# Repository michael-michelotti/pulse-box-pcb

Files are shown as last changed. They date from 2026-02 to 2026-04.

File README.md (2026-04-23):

# Pulse Box PCB

KiCad 9.0 hardware designs for the [PulseBox](https://github.com/michael-michelotti/pulse-box-esp) project — a modular LED grid system with a central controller driving a dynamically reconfigurable array of 8x8 LED panels. This repo holds the schematics, board layouts, and JLCPCB manufacturing outputs for all board revisions.

This is meant as a companion to the [main PulseBox repo](https://github.com/michael-michelotti/pulse-box-esp) — see that repo for the full system overview.

---

## Controller v1 (`Pulse_Box_PCB_v1/`)

<!-- TODO: Replace with labeled photo of v1 controller board -->

Controller v1

Original controller, fabricated and assembled by JLCPCB. 2-layer board built around an **STM32F407VGT6** (ARM Cortex-M4, LQFP-100). Power comes in through a 5.5mm barrel jack and is regulated by a **TPSM53604RDA** 4A buck module (down to 5V), followed by an **AP2112K-3.3** LDO for the 3.3V MCU rail. LED data is level-shifted from 3.3V to 5V through a **SN74LV1T34** before driving the WS2812B chain. USB Micro-B for serial/flashing.

---

## Controller v2 (`Pulse_Box_PCB_v2/`)

<!-- TODO: Replace with labeled photo of v2 controller board -->

Controller v2

Redesigned controller centered on the **ESP32-S3-WROOM-1** module (WiFi, BLE, dual-core). 2-layer, 80mm x 80mm. The barrel jack is replaced with a 24V input to match the rest of the panel bus, and the buck module is swapped for a **discrete TPS54560B** design (24V→5V, 5A) with an **AP2112K-3.3** LDO for the 3.3V rail. USB-C exposes the ESP32-S3's native USB-JTAG for debug. Dual **SN74LV1T34** level shifters drive LED data north and west, and panel interconnect is 8-pin (24V, GND, RS-485 A/B, sense, LED data).

---

## Panel v1 (`Pulse_Box_Panel_v1/`)

<!-- TODO: Replace with labeled photo of panel board -->

Panel v1

LED panel board, 2-layer, 80mm x 80mm. Runs an **STM32G071C8** (Cortex-M0+, LQFP-48) with four USARTs — one per edge — so adjacent panels mate face-to-face with no crossover. Power mirrors the v2 controller: 24V bus in, discrete buck to 5V for the LEDs, **AP2112K-3.3** LDO for the 3.3V MCU rail. LED data routing uses two **74HC4051** 8-channel analog muxes (one for input, one for output) so any edge can be selected as the data in/out for the panel's 8x8 grid. Four JST XH 11-position edge connectors carry 24V, GND, UART TX/RX, sense, and LED data. SWD header for debug; UART bootloader available on PA2/PA3 as a recovery path.

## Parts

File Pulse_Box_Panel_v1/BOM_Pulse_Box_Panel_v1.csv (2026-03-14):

Comment | Designator | Footprint | JLCPCB Part #
10uF | C1,C2,C3,C9,C11 | Capacitor_SMD:C_0805_2012Metric | C440198
11nF | C4 | Capacitor_SMD:C_0805_2012Metric | C710944
8.2pF | C5 | Capacitor_SMD:C_0402_1005Metric | C1579
100nF | C6,C10,C12,C13,C16 | Capacitor_SMD:C_0402_1005Metric | C1525
47uF | C7,C8 | Capacitor_SMD:C_0805_2012Metric | C76636
20pF | C14,C15 | Capacitor_SMD:C_0402_1005Metric | C1554
100uF | C17,C18,C19 | Capacitor_SMD:C_Elec_8x10.2 | C3352
SS310 | D1 | Diode_SMD:D_SMB | C14651
LED | D3,D4 | LED_SMD:LED_0402_1005Metric | C71911
Conn_01x11 | J1,J2,J3,J4 | Connector_JST:JST_XH_B11B-XH-A_1x11_P2.50mm_Vertical | C158031
Conn_01x03 | J5,J6 | Connector_JST:JST_PH_B3B-PH-K_1x03_P2.00mm_Vertical | C131339
Conn_01x04_Pin | J7 | Connector_PinHeader_2.54mm:PinHeader_1x04_P2.54mm_Vertical | C124378
Conn_01x03 | J8 | Connector_PinHeader_2.54mm:PinHeader_1x03_P2.54mm_Vertical | C49257
Conn_02x05_Odd_Even | J9 | Connector_PinHeader_1.27mm:PinHeader_2x05_P1.27mm_Vertical | C239059
10uH | L1 | Inductor_SMD:L_TechFuse_SL1040 | C22463839
274k | R1 | Resistor_SMD:R_0402_1005Metric | C27004
15.8k | R2 | Resistor_SMD:R_0402_1005Metric | C26956
60k | R3 | Resistor_SMD:R_0402_1005Metric | C25911
11.5k | R4 | Resistor_SMD:R_0402_1005Metric | C159139
470 | R11,R12 | Resistor_SMD:R_0402_1005Metric | C25117
STM32G0B1CBTx | U1 | Package_QFP:LQFP-48_7x7mm_P0.5mm | C529341
TPS54560BDDA | U2 | Package_SO:Texas_R-PDSO-G8_EP2.95x4.9mm_Mask2.4x3.1mm_ThermalVias | C1850354
AP2112K-3.3 | U3 | Package_TO_SOT_SMD:SOT-23-5 | C3021085
74HCT4051 | U4,U5 | Package_SO:TSSOP-16_4.4x5mm_P0.65mm | C192055
8MHz Crystal | Y1 | Crystal:Crystal_SMD_3225-4Pin_3.2x2.5mm | C57131

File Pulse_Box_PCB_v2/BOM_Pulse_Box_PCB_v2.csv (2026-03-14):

Comment | Designator | Footprint | JLCPCB Part #
470uF | C1 | Capacitor_SMD:CP_Elec_10x12.6 | C90272
10uF | C2,C3,C4 | Capacitor_SMD:C_0805_2012Metric | C440198
11nF | C5 | Capacitor_SMD:C_0805_2012Metric | C710944
8.2pF | C6 | Capacitor_SMD:C_0402_1005Metric | C1579
100nF | C7,C12,C13,C14,C15,C16 | Capacitor_SMD:C_0402_1005Metric | C1525
47uF | C8,C9 | Capacitor_SMD:C_0805_2012Metric | C76636
4.7uF | C10,C11 | Capacitor_SMD:C_0805_2012Metric | C1779
22uF | C17 | Capacitor_SMD:C_1206_3216Metric_Pad1.33x1.80mm_HandSolder | C12891
1uF | C18 | Capacitor_SMD:C_0402_1005Metric | C52923
SS310 | D1 | Diode_SMD:D_SMB | C14651
LED | D3,D4 | LED_SMD:LED_0402_1005Metric | C71911
Screw_Terminal_01x02 | J1 | TerminalBlock_Phoenix:TerminalBlock_Phoenix_MKDS-1,5-2-5.08_1x02_P5.08mm_Horizontal | C8465
Conn_01x11 | J2,J3 | Connector_JST:JST_XH_B11B-XH-A_1x11_P2.50mm_Vertical | C158031
Conn_01x03 | J4,J5 | Connector_JST:JST_PH_B3B-PH-K_1x03_P2.00mm_Vertical | C131339
Conn_01x03_Pin | J6 | Connector_PinHeader_2.54mm:PinHeader_1x03_P2.54mm_Vertical | C49257
Conn_01x04 | J7 | Connector_PinHeader_2.54mm:PinHeader_1x04_P2.54mm_Vertical | C124378
10uH | L1 | Inductor_SMD:L_TechFuse_SL1040 | C22463839
USB_C_Plug_USB2.0 | P1 | Connector_USB:USB_C_Receptacle_HRO_TYPE-C-31-M-12 | C165948
274k | R1 | Resistor_SMD:R_0402_1005Metric | C27004
15.8k | R2 | Resistor_SMD:R_0402_1005Metric | C26956
60k | R3 | Resistor_SMD:R_0402_1005Metric | C25911
11.5k | R4 | Resistor_SMD:R_0402_1005Metric | C159139
22 | R5,R6 | Resistor_SMD:R_0402_1005Metric | C25092
10k | R7,R8,R11,R12 | Resistor_SMD:R_0402_1005Metric | C25744
470 | R9,R10 | Resistor_SMD:R_0402_1005Metric | C25117
5.1k | R13 | Resistor_SMD:R_0402_1005Metric | C25905
SW_Push | SW1,SW2 | Button_Switch_SMD:SW_Push_SPST_NO_Alps_SKRK | C398055
ESP32-S3-WROOM-1 | U1 | RF_Module:ESP32-S3-WROOM-1 | C2913197
USBLC6-2SC6 | U2 | Package_TO_SOT_SMD:SOT-23-6 | C558442
TPS54560BDDA | U3 | Package_SO:Texas_R-PDSO-G8_EP2.95x4.9mm_Mask2.4x3.1mm_ThermalVias | C1850354
SN74LV1T34DBV | U4,U6 | Package_TO_SOT_SMD:SOT-23-5 | C100024
74LVC1G3157 | U5 | Package_TO_SOT_SMD:SOT-23-6 | C10426
AP2114-3.3TRG1 | U7 | Package_TO_SOT_SMD:SOT-223-3_TabPin2 | C460314

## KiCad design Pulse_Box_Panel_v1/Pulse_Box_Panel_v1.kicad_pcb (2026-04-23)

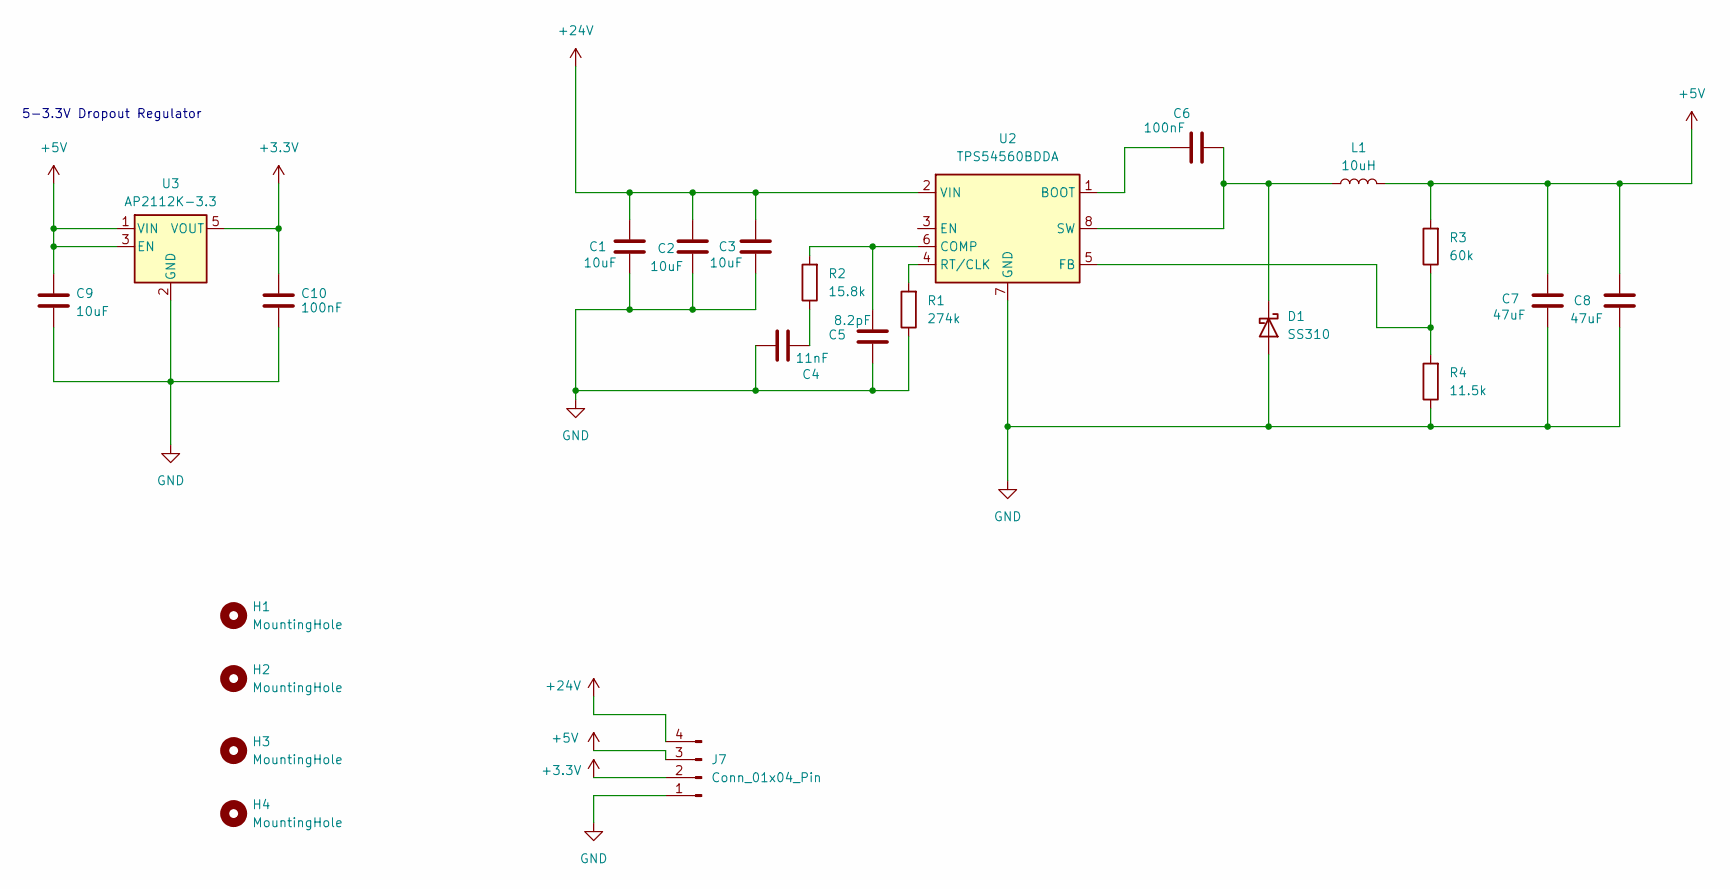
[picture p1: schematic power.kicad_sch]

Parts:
C1, C2, C3: 10uF; C_0805_2012Metric; JLCPCB Part # C440198
C4: 11nF; C_0805_2012Metric; JLCPCB Part # C710944
C5: 8.2pF; C_0402_1005Metric; JLCPCB Part # C1579
C6: 100nF; C_0402_1005Metric; JLCPCB Part # C1525
C7, C8: 47uF; C_0805_2012Metric; JLCPCB Part # C76636
C9: 10uF; C_0805_2012Metric; MFR PN CL21A106KAYNNNE; JLCPCB PN C15850
C10: 100nF; C_0402_1005Metric; MFR PN CL21A475KAQNNNE; JLCPCB PN C1779
D1: SS310; D_SMB; JLCPCB Part # C14651
H1, H2, H3, H4: MountingHole; MountingHole_3.2mm_M3
J7: Conn_01x04_Pin; PinHeader_1x04_P2.54mm_Vertical; JLCPCB Part # C124378
L1: 10uH; L_TechFuse_SL1040; JLCPCB Part # C22463839
R1: 274k; R_0402_1005Metric; JLCPCB Part # C27004
R2: 15.8k; R_0402_1005Metric; JLCPCB Part # C26956
R3: 60k; R_0402_1005Metric; JLCPCB Part # C25911
R4: 11.5k; R_0402_1005Metric; JLCPCB Part # C159139
U2: TPS54560BDDA; Texas_R-PDSO-G8_EP2.95x4.9mm_Mask2.4x3.1mm_ThermalVias; JLCPCB Part # C1850354
U3: AP2112K-3.3; SOT-23-5; MFR PN AP2112K-3.3; JLCPCB PN C23380830

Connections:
+3.3V: C10.1, J7.2, U3.5 (VOUT); also elsewhere on the board
+5V: C7.1, C8.1, C9.1, J7.3, L1.2, R3.2, U3.1 (VIN), U3.3 (EN); also elsewhere on the board
+24V: C1.1, C2.1, C3.1, J7.4, U2.2 (VIN); also elsewhere on the board
GND: C1.2, C2.2, C3.2, C4.1, C5.2, C7.2, C8.2, C9.2, C10.2, D1.2 (A), J7.1, R1.1, R4.1, U2.7 (GND), U2.9 (GND), U3.2 (GND); also elsewhere on the board
unnamed: C4.2, R2.1
unnamed: C6.2, D1.1 (K), L1.1, U2.8 (SW)
unnamed: C6.1, U2.1 (BOOT)
unnamed: C5.1, R2.2, U2.6 (COMP)
unnamed: R3.1, R4.2, U2.5 (FB)
unnamed: R1.2, U2.4 (RT/CLK)

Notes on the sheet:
5-3.3V Dropout Regulator

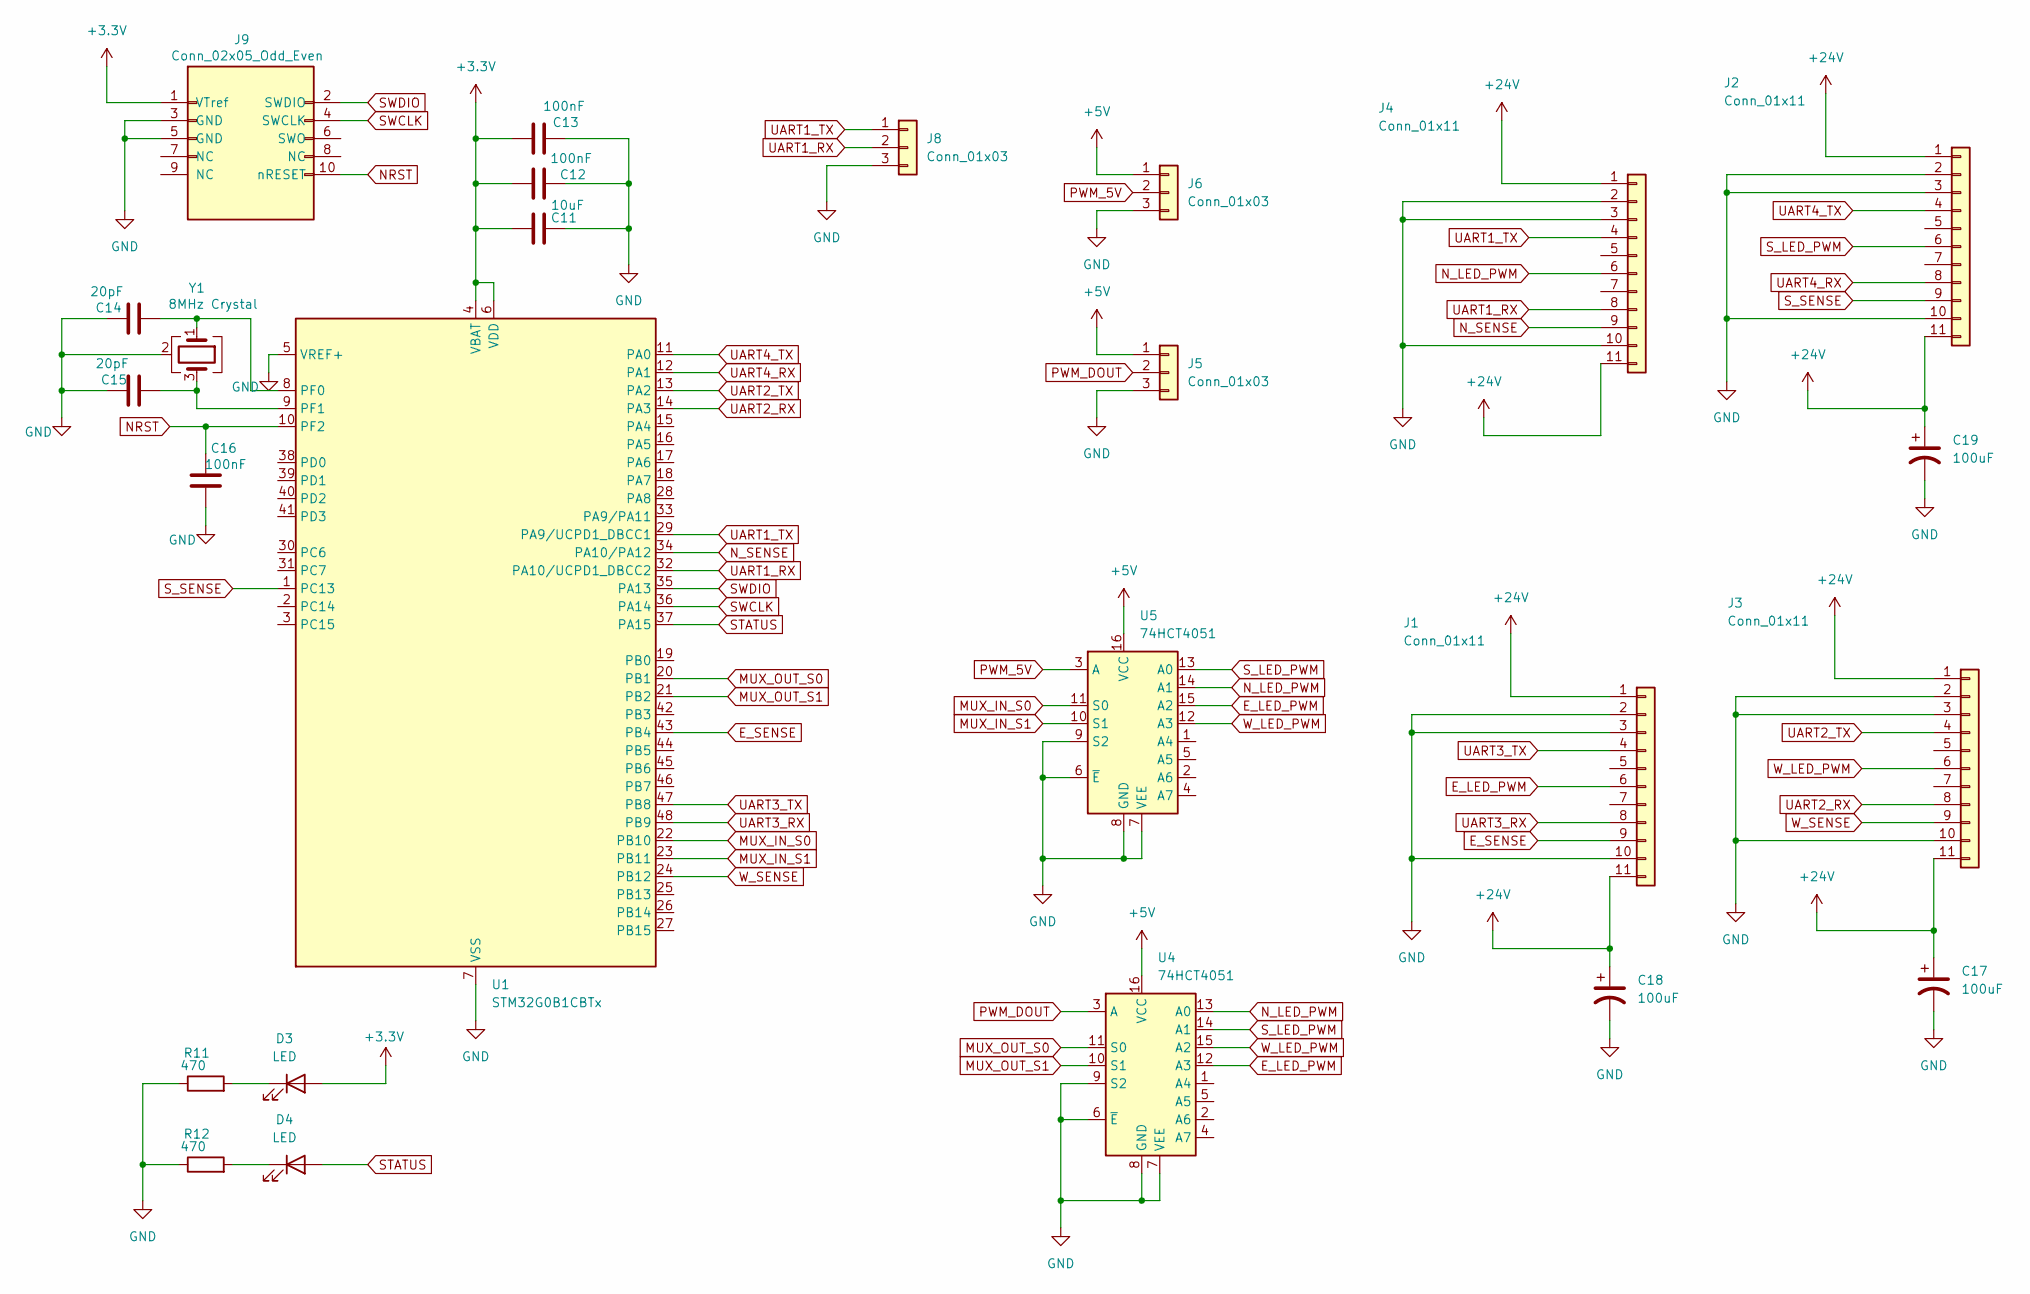
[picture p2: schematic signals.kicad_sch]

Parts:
C11: 10uF; C_0805_2012Metric; JLCPCB Part # C440198
C12, C13, C16: 100nF; C_0402_1005Metric; JLCPCB Part # C1525
C14, C15: 20pF; C_0402_1005Metric; JLCPCB Part # C1554
C17, C18, C19: 100uF; C_Elec_8x10.2; JLCPCB Part # C3352
D3, D4: LED; LED_0402_1005Metric; JLCPCB Part # C71911
J1, J2, J3, J4: Conn_01x11; JST_XH_B11B-XH-A_1x11_P2.50mm_Vertical; JLCPCB Part # C158031
J5, J6: Conn_01x03; JST_PH_B3B-PH-K_1x03_P2.00mm_Vertical; JLCPCB Part # C131339
J8: Conn_01x03; PinHeader_1x03_P2.54mm_Vertical; JLCPCB Part # C49257
J9: Conn_02x05_Odd_Even; PinHeader_2x05_P1.27mm_Vertical; MFR PN 20021111-00010T4LF; JLCPCB PN C239059
R11, R12: 470; R_0402_1005Metric; JLCPCB Part # C25117
U1: STM32G0B1CBTx; LQFP-48_7x7mm_P0.5mm; JLCPCB Part # C529341
U4, U5: 74HCT4051; TSSOP-16_4.4x5mm_P0.65mm; JLCPCB Part # C192055
Y1: 8MHz Crystal; Crystal_SMD_3225-4Pin_3.2x2.5mm; MFR PN 1C208000BC0R; JLCPCB PN C57131

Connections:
+3.3V: C11.1, C12.1, C13.1, D3.2 (A), J9.1 (VTref), U1.4 (VBAT), U1.6 (VDD); also elsewhere on the board
+5V: J5.1, J6.1, U4.16 (VCC), U5.16 (VCC); also elsewhere on the board
+24V: C17.1, C18.1, C19.1, J1.1, J1.11, J2.1, J2.11, J3.1, J3.11, J4.1, J4.11; also elsewhere on the board
E_LED_PWM: J1.6, U4.12 (A3), U5.15 (A2)
E_SENSE: J1.9, U1.43 (PB4)
GND: C11.2, C12.2, C13.2, C14.1, C15.1, C16.1, C17.2, C18.2, C19.2, J1.2, J1.3, J1.10, J2.2, J2.3, J2.10, J3.2, J3.3, J3.10, J4.2, J4.3, J4.10, J5.3, J6.3, J8.3, J9.3 (GND), J9.5 (GND), R11.1, R12.1, U1.5 (VREF+), U1.7 (VSS), U4.6 (~E), U4.7 (VEE), U4.8 (GND), U4.9 (S2), U5.6 (~E), U5.7 (VEE), U5.8 (GND), U5.9 (S2), Y1.2 (G), Y1.4 (G); also elsewhere on the board
MUX_IN_S0: U1.22 (PB10), U5.11 (S0)
MUX_IN_S1: U1.23 (PB11), U5.10 (S1)
MUX_OUT_S0: U1.20 (PB1), U4.11 (S0)
MUX_OUT_S1: U1.21 (PB2), U4.10 (S1)
NRST: C16.2, J9.10 (nRESET), U1.10 (PF2)
N_LED_PWM: J4.6, U4.13 (A0), U5.14 (A1)
N_SENSE: J4.9, U1.34 (PA10/PA12)
unnamed: D3.1 (K), R11.2
unnamed: D4.1 (K), R12.2
unnamed: C14.2, U1.8 (PF0), Y1.1
unnamed: C15.2, U1.9 (PF1), Y1.3
PWM_5V: J6.2, U5.3 (A)
PWM_DOUT: J5.2, U4.3 (A)
STATUS: D4.2 (A), U1.37 (PA15)
SWCLK: J9.4 (SWCLK), U1.36 (PA14)
SWDIO: J9.2 (SWDIO), U1.35 (PA13)
S_LED_PWM: J2.6, U4.14 (A1), U5.13 (A0)
S_SENSE: J2.9, U1.1 (PC13)
UART1_RX: J4.8, J8.2, U1.32 (PA10/UCPD1_DBCC2)
UART1_TX: J4.4, J8.1, U1.29 (PA9/UCPD1_DBCC1)
UART2_RX: J3.8, U1.14 (PA3)
UART2_TX: J3.4, U1.13 (PA2)
UART3_RX: J1.8, U1.48 (PB9)
UART3_TX: J1.4, U1.47 (PB8)
UART4_RX: J2.8, U1.12 (PA1)
UART4_TX: J2.4, U1.11 (PA0)
W_LED_PWM: J3.6, U4.15 (A2), U5.12 (A3)
W_SENSE: J3.9, U1.24 (PB12)

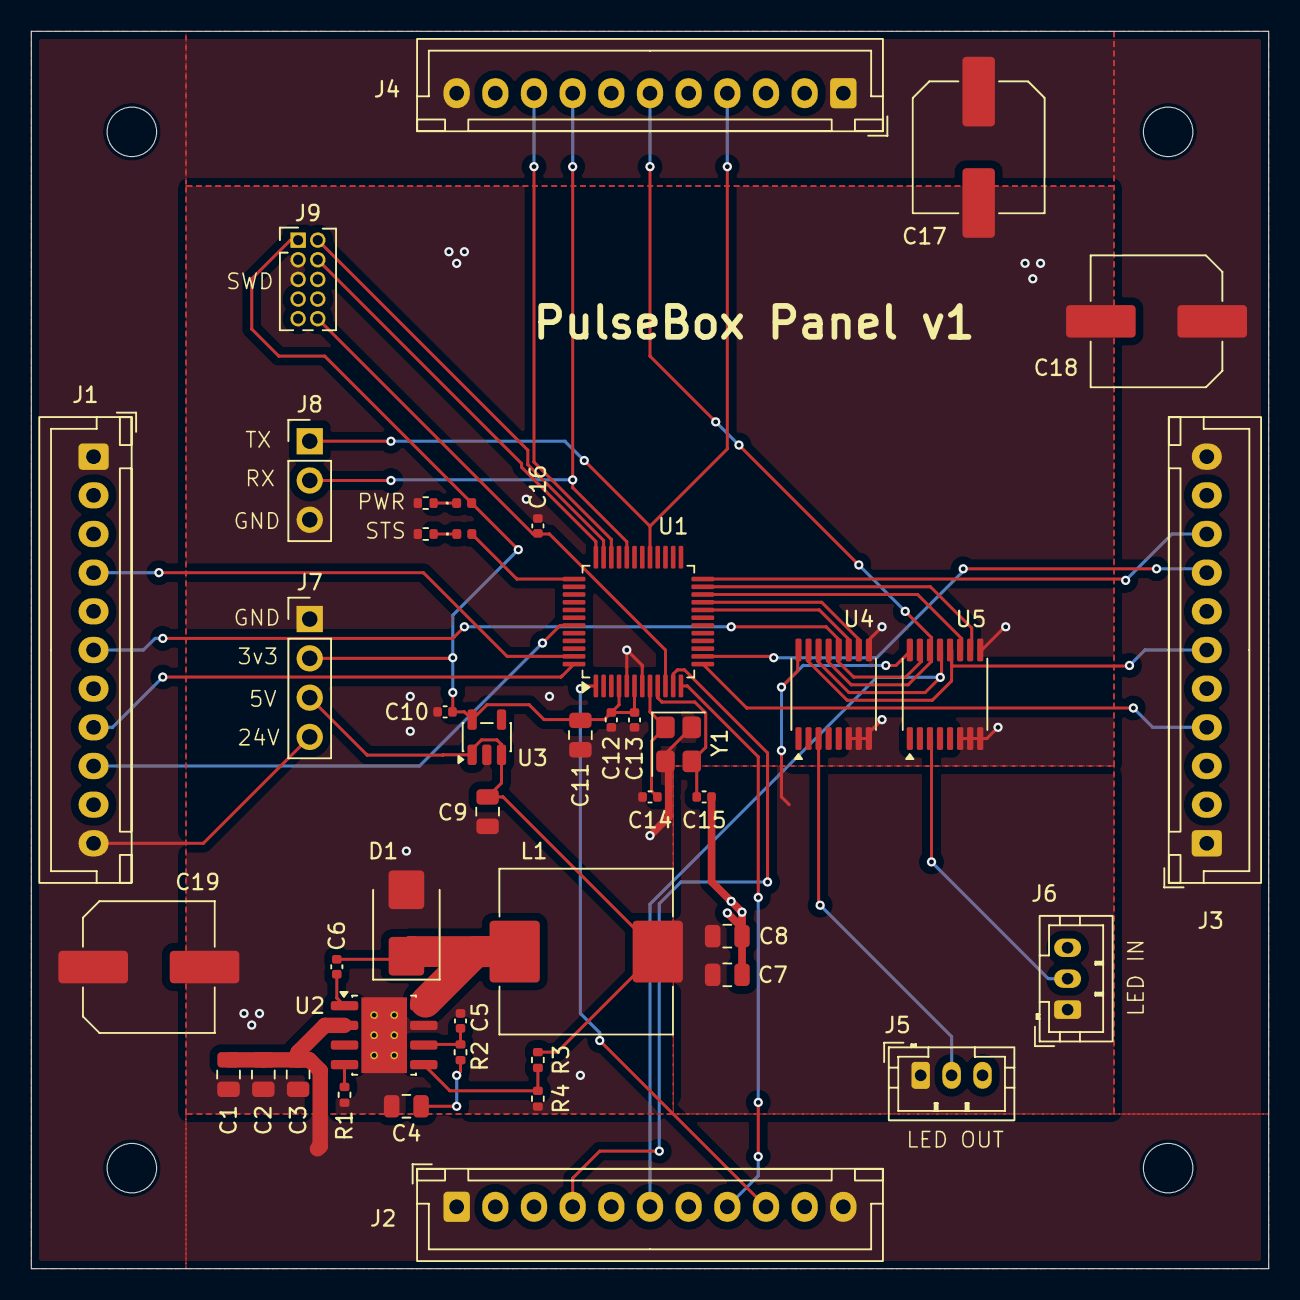
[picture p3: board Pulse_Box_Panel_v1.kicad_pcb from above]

Board: 2 copper layers, 80.0 x 80.0 mm, 48 parts (0 on the bottom side), 40 nets.

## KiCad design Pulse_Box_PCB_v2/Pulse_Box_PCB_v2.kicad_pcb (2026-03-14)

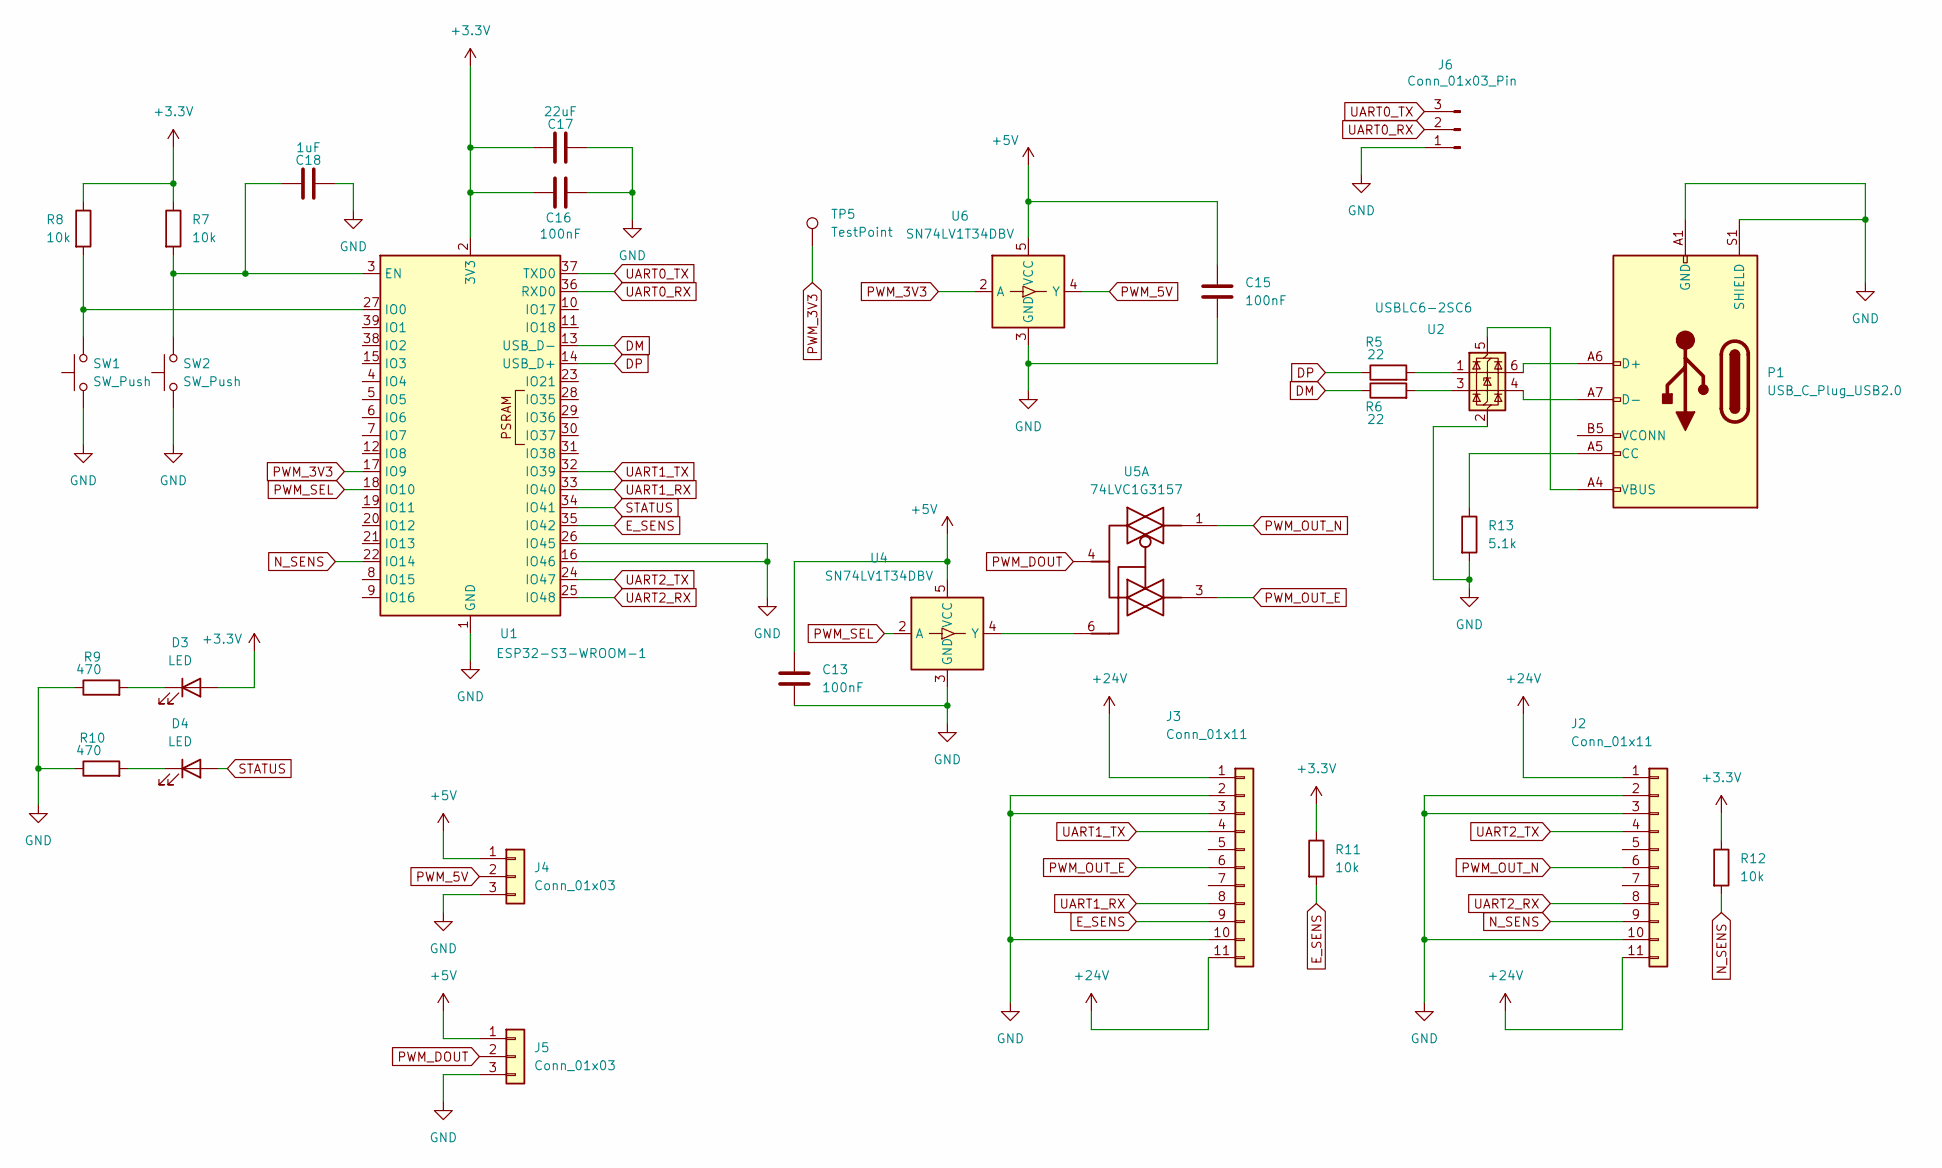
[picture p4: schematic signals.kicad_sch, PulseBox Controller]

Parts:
C13, C15, C16: 100nF; C_0402_1005Metric; JLCPCB Part # C1525
C17: 22uF; C_1206_3216Metric_Pad1.33x1.80mm_HandSolder; JLCPCB Part # C12891
C18: 1uF; C_0402_1005Metric; JLCPCB Part # C52923
D3, D4: LED; LED_0402_1005Metric; JLCPCB Part # C71911
J2, J3: Conn_01x11; JST_XH_B11B-XH-A_1x11_P2.50mm_Vertical; JLCPCB Part # C158031
J4, J5: Conn_01x03; JST_PH_B3B-PH-K_1x03_P2.00mm_Vertical; JLCPCB Part # C131339
J6: Conn_01x03_Pin; PinHeader_1x03_P2.54mm_Vertical; JLCPCB Part # C49257
P1: USB_C_Plug_USB2.0; USB_C_Receptacle_HRO_TYPE-C-31-M-12; JLCPCB Part # C165948
R5, R6: 22; R_0402_1005Metric; JLCPCB Part # C25092
R7, R8, R11, R12: 10k; R_0402_1005Metric; JLCPCB Part # C25744
R9, R10: 470; R_0402_1005Metric; JLCPCB Part # C25117
R13: 5.1k; R_0402_1005Metric; JLCPCB Part # C25905
SW1, SW2: SW_Push; SW_Push_SPST_NO_Alps_SKRK; JLCPCB Part # C398055
TP5: TestPoint; TestPoint_Pad_2.0x2.0mm
U1: ESP32-S3-WROOM-1; JLCPCB Part # C2913197
U2: USBLC6-2SC6; SOT-23-6; JLCPCB Part # C558442
U4, U6: SN74LV1T34DBV; SOT-23-5; JLCPCB Part # C100024
U5: 74LVC1G3157; SOT-23-6; JLCPCB Part # C10426

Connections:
+3.3V: C16.2, C17.2, D3.2 (A), R7.1, R8.1, R11.1, R12.1, U1.2 (3V3); also elsewhere on the board
+5V: C13.1, C15.1, J4.1, J5.1, U4.5 (VCC), U6.5 (VCC); also elsewhere on the board
+24V: J2.1, J2.11, J3.1, J3.11; also elsewhere on the board
DM: R6.1, U1.13 (USB_D-)
DP: R5.1, U1.14 (USB_D+)
E_SENS: J3.9, R11.2, U1.35 (IO42)
GND: C13.2, C15.2, C16.1, C17.1, C18.1, J2.2, J2.3, J2.10, J3.2, J3.3, J3.10, J4.3, J5.3, J6.1, P1.A1 (GND), P1.A12 (GND), P1.B1 (GND), P1.B12 (GND), P1.S1 (SHIELD), R9.1, R10.1, R13.2, SW1.1, SW2.1, U1.1 (GND), U1.16 (IO46), U1.26 (IO45), U1.40 (GND), U1.41 (GND), U2.2 (GND), U4.3 (GND), U6.3 (GND); also elsewhere on the board
N_SENS: J2.9, R12.2, U1.22 (IO14)
unnamed: D3.1 (K), R9.2
unnamed: D4.1 (K), R10.2
unnamed: P1.A5 (CC), R13.1
unnamed: P1.A6 (D+), U2.6 (I/O1)
unnamed: P1.A7 (D-), U2.4 (I/O2)
unnamed: R5.2, U2.1 (I/O1)
unnamed: R6.2, U2.3 (I/O2)
unnamed: C18.2, R7.2, SW2.2, U1.3 (EN)
unnamed: R8.2, SW1.2, U1.27 (IO0)
unnamed: P1.A4 (VBUS), P1.A9 (VBUS), P1.B4 (VBUS), P1.B9 (VBUS), U2.5 (VBUS)
unnamed: U4.4 (Y), U5.6
PWM_3V3: TP5.1, U1.17 (IO9), U6.2 (A)
PWM_5V: J4.2, U6.4 (Y)
PWM_DOUT: J5.2, U5.4
PWM_OUT_E: J3.6, U5.3
PWM_OUT_N: J2.6, U5.1
PWM_SEL: U1.18 (IO10), U4.2 (A)
STATUS: D4.2 (A), U1.34 (IO41)
UART0_RX: J6.2, U1.36 (RXD0)
UART0_TX: J6.3, U1.37 (TXD0)
UART1_RX: J3.8, U1.33 (IO40)
UART1_TX: J3.4, U1.32 (IO39)
UART2_RX: J2.8, U1.25 (IO48)
UART2_TX: J2.4, U1.24 (IO47)

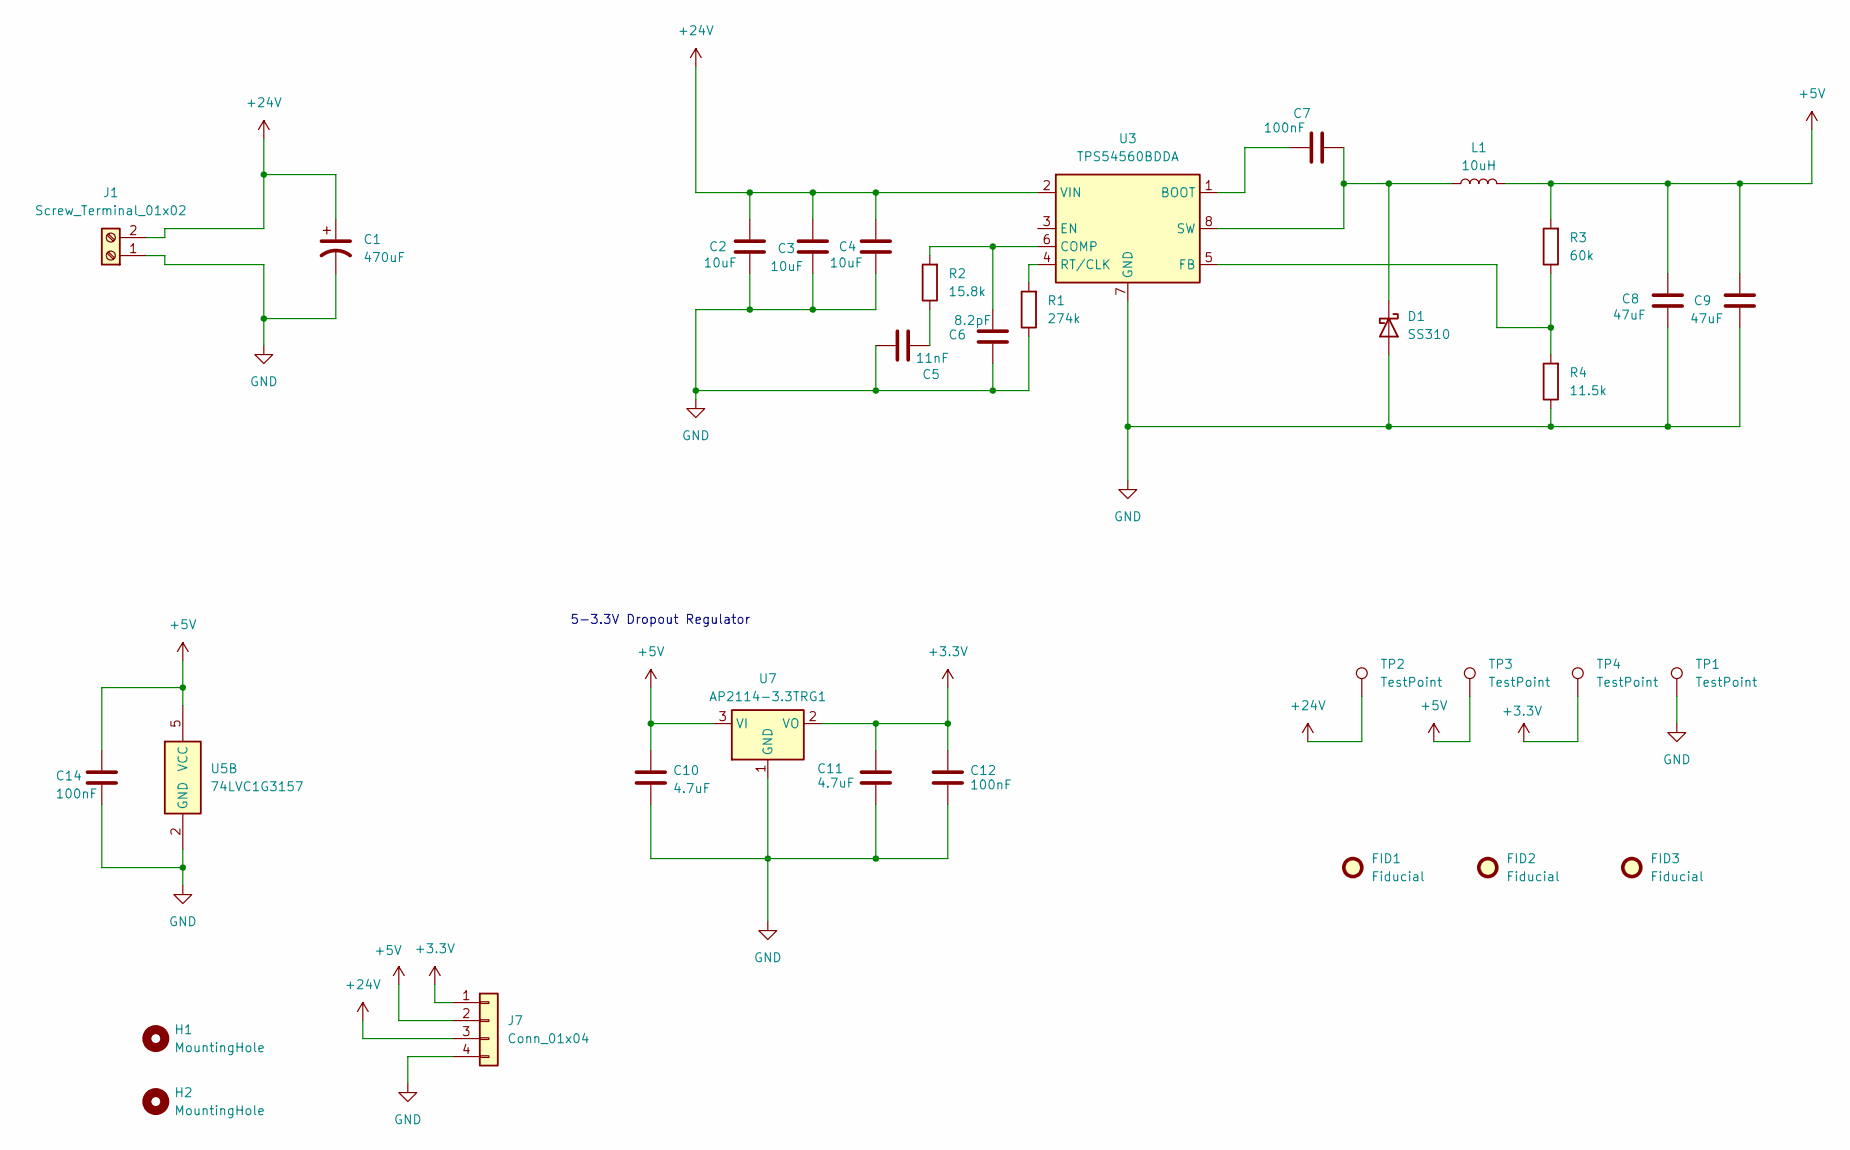
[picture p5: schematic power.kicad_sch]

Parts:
C1: 470uF; CP_Elec_10x12.6; JLCPCB Part # C90272
C2, C3, C4: 10uF; C_0805_2012Metric; JLCPCB Part # C440198
C5: 11nF; C_0805_2012Metric; JLCPCB Part # C710944
C6: 8.2pF; C_0402_1005Metric; JLCPCB Part # C1579
C7, C14: 100nF; C_0402_1005Metric; JLCPCB Part # C1525
C8, C9: 47uF; C_0805_2012Metric; JLCPCB Part # C76636
C10: 4.7uF; C_0805_2012Metric; MFR PN CL21A106KAYNNNE; JLCPCB PN C15850
C11: 4.7uF; C_0805_2012Metric; MFR PN CL21A475KAQNNNE; JLCPCB PN C1779
C12: 100nF; C_0402_1005Metric; MFR PN CL21A475KAQNNNE; JLCPCB PN C1779
D1: SS310; D_SMB; JLCPCB Part # C14651
FID1, FID2, FID3: Fiducial; Fiducial_0.5mm_Mask1.5mm
H1, H2: MountingHole; MountingHole_3.2mm_M3
J1: Screw_Terminal_01x02; TerminalBlock_Phoenix_MKDS-1,5-2-5.08_1x02_P5.08mm_Horizont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; JLCPCB Part # C8465
J7: Conn_01x04; PinHeader_1x04_P2.54mm_Vertical; JLCPCB Part # C124378
L1: 10uH; L_TechFuse_SL1040; JLCPCB Part # C22463839
R1: 274k; R_0402_1005Metric; JLCPCB Part # C27004
R2: 15.8k; R_0402_1005Metric; JLCPCB Part # C26956
R3: 60k; R_0402_1005Metric; JLCPCB Part # C25911
R4: 11.5k; R_0402_1005Metric; JLCPCB Part # C159139
TP1, TP2, TP3, TP4: TestPoint; TestPoint_Pad_2.0x2.0mm
U3: TPS54560BDDA; Texas_R-PDSO-G8_EP2.95x4.9mm_Mask2.4x3.1mm_ThermalVias; JLCPCB Part # C1850354
U5: 74LVC1G3157; SOT-23-6; JLCPCB Part # C10426
U7: AP2114-3.3TRG1; SOT-223-3_TabPin2; JLCPCB Part # C460314

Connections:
+3.3V: C11.1, C12.1, J7.1, TP4.1, U7.2 (VO); also elsewhere on the board
+5V: C8.1, C9.1, C10.1, C14.1, J7.2, L1.2, R3.2, TP3.1, U5.5 (VCC), U7.3 (VI); also elsewhere on the board
+24V: C1.1, C2.1, C3.1, C4.1, J1.2, J7.3, TP2.1, U3.2 (VIN); also elsewhere on the board
GND: C1.2, C2.2, C3.2, C4.2, C5.1, C6.2, C8.2, C9.2, C10.2, C11.2, C12.2, C14.2, D1.2 (A), J1.1, J7.4, R1.1, R4.1, TP1.1, U3.7 (GND), U3.9 (GND), U5.2 (GND), U7.1 (GND); also elsewhere on the board
unnamed: C5.2, R2.1
unnamed: C7.2, D1.1 (K), L1.1, U3.8 (SW)
unnamed: C7.1, U3.1 (BOOT)
unnamed: C6.1, R2.2, U3.6 (COMP)
unnamed: R3.1, R4.2, U3.5 (FB)
unnamed: R1.2, U3.4 (RT/CLK)

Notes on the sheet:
5-3.3V Dropout Regulator

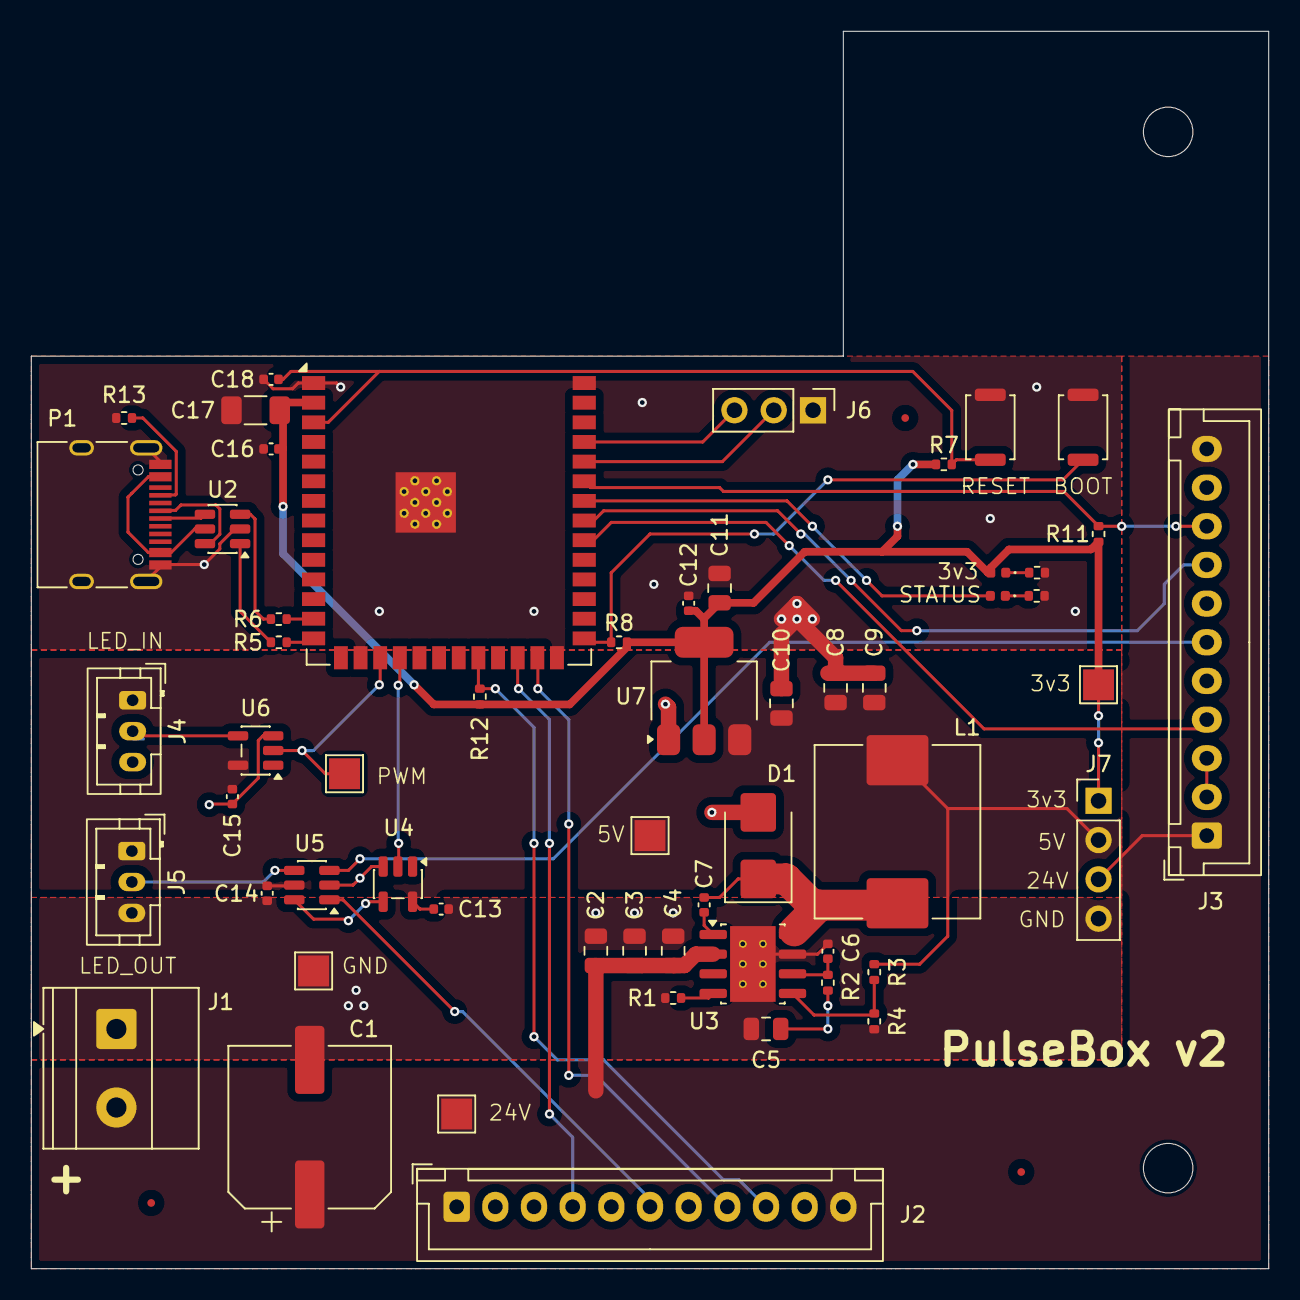
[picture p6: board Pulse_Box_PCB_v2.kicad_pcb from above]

Board: 2 copper layers, 80.0 x 80.0 mm, 62 parts (0 on the bottom side), 38 nets.

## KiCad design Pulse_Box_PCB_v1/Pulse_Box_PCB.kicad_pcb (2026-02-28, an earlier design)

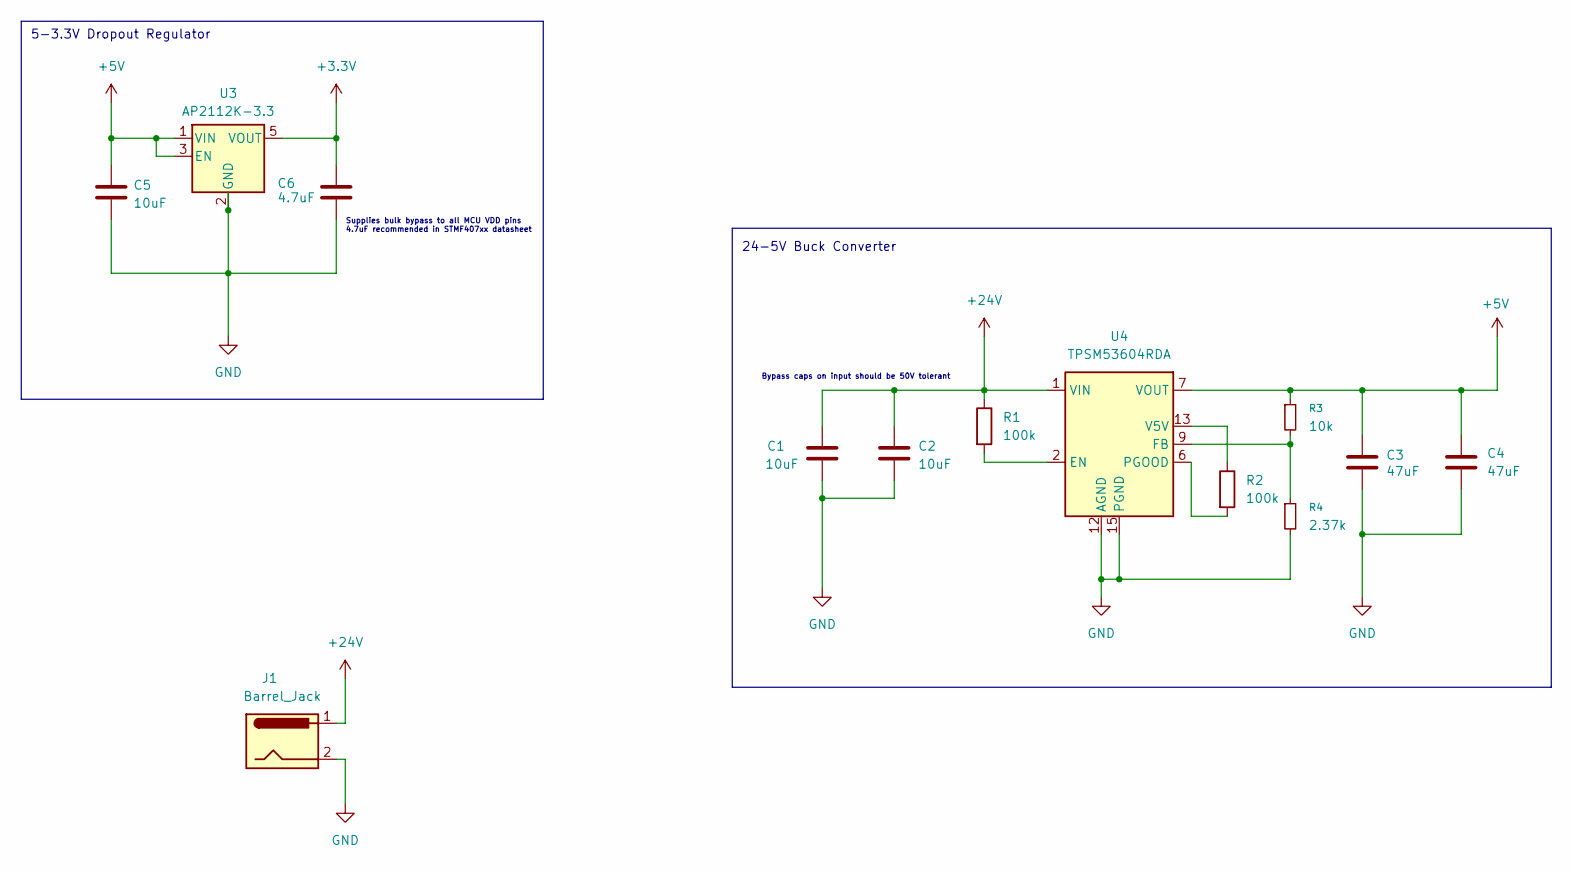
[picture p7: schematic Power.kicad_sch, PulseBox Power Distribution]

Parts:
C1, C2, C5: 10uF; C_0805_2012Metric; MFR PN CL21A106KAYNNNE; JLCPCB PN C15850
C3, C4: 47uF; C_1210_3225Metric; MFR PN GRM32ER61C476KE15L; JLCPCB PN C77101
C6: 4.7uF; C_0805_2012Metric; MFR PN CL21A475KAQNNNE; JLCPCB PN C1779
J1: Barrel_Jack; XKB_DC-005-5A-2.0; MFR PN DC-005-5A-2.0; JLCPCB PN C381116
R1, R2: 100k; R_0402_1005Metric; MFR PN 0402WGF1003TCE; JLCPCB PN C25741
R3: 10k; R_0402_1005Metric; MFR PN 0402WGF1002TCE; JLCPCB PN C25744
R4: 2.37k; R_0402_1005Metric; MFR PN RC0402FR-072K37L; JLCPCB PN C294439
U3: AP2112K-3.3; SOT-23-5; MFR PN AP2112K-3.3; JLCPCB PN C23380830
U4: TPSM53604RDA; Texas_B3QFN-14-1EP_5x5.5mm_P0.65mm_ThermalVia; MFR PN TPSM53604; JLCPCB PN C2868001

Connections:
+3.3V: C6.1, U3.5 (VOUT); also elsewhere on the board
+5V: C3.1, C4.1, C5.1, R3.1, U3.1 (VIN), U3.3 (EN), U4.7 (VOUT), U4.8 (VOUT); also elsewhere on the board
+24V: C1.1, C2.1, J1.1, R1.1, U4.1 (VIN), U4.14 (VIN); also elsewhere on the board
GND: C1.2, C2.2, C3.2, C4.2, C5.2, C6.2, J1.2, R4.2, U3.2 (GND), U4.3 (PGND), U4.10 (PGND), U4.11 (PGND), U4.12 (AGND), U4.15 (PGND); also elsewhere on the board
unnamed: R1.2, U4.2 (EN)
unnamed: R3.2, R4.1, U4.9 (FB)
unnamed: R2.2, U4.6 (PGOOD)
unnamed: R2.1, U4.13 (V5V)

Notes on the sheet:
5-3.3V Dropout Regulator
Bypass caps on input should be 50V tolerant
24-5V Buck Converter
Supplies bulk bypass to all MCU VDD pins 4.7uF recommended in STMF407xx datasheet

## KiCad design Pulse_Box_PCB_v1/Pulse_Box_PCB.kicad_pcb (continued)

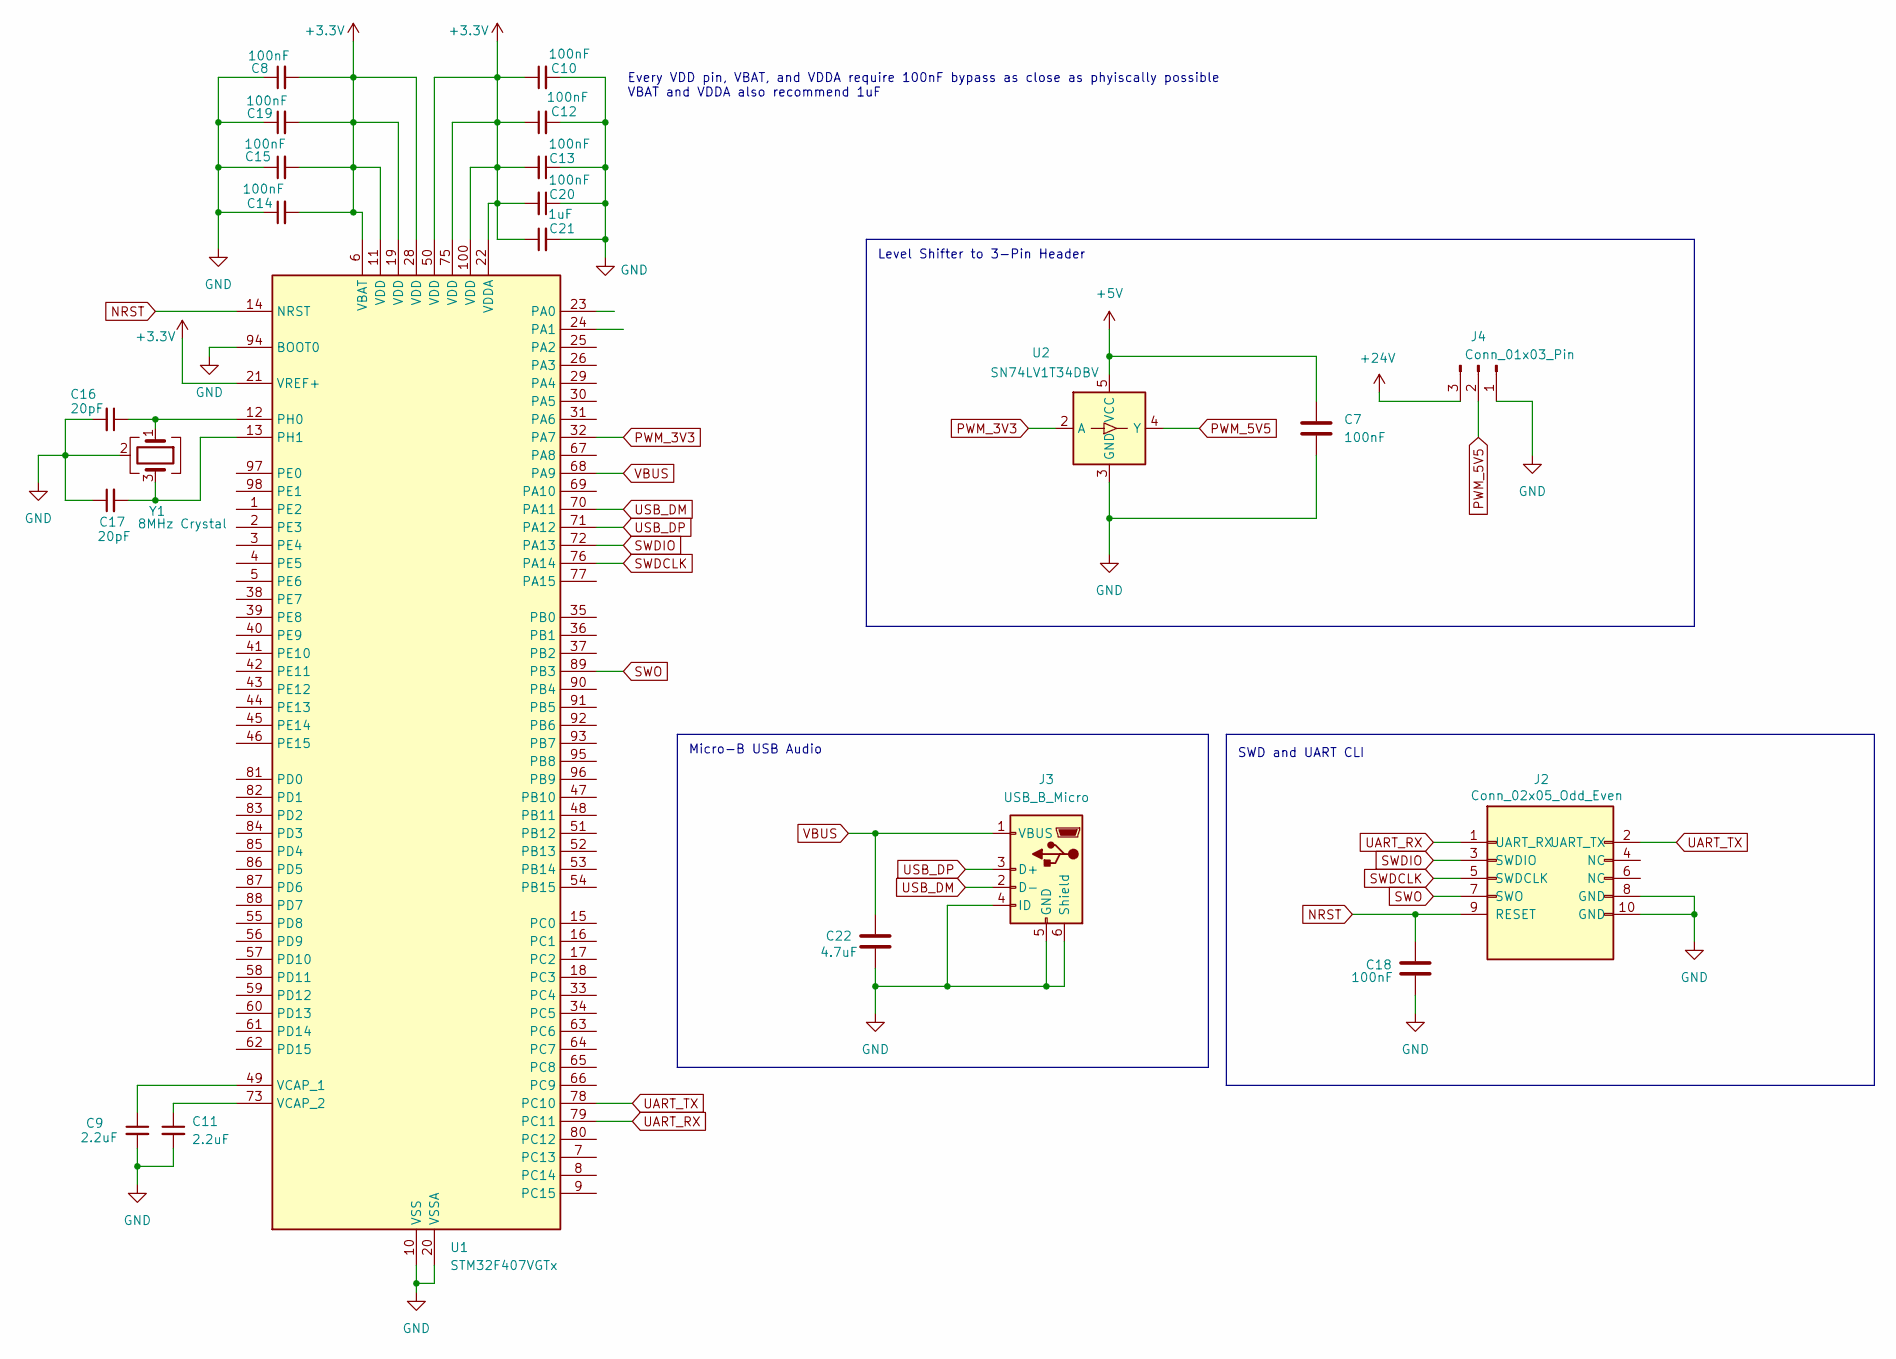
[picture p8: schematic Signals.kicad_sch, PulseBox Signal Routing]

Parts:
C7, C8, C10, C12, C13, C14, C15, C18, C19, C20: 100nF; C_0402_1005Metric; MFR PN CL05B104KO5NNNC; JLCPCB PN C1525
C9, C11: 2.2uF; C_0603_1608Metric; MFR PN CL10A225KO8NNNC; JLCPCB PN C23630
C16, C17: 20pF; C_0402_1005Metric; MFR PN 0402CG200J500NT; JLCPCB PN C1554
C21: 1uF; C_0402_1005Metric; MFR PN CL05A105KA5NQNC; JLCPCB PN C52923
C22: 4.7uF; C_0805_2012Metric; MFR PN CL21A475KAQNNNE; JLCPCB PN C1779
J2: Conn_02x05_Odd_Even; PinHeader_2x05_P1.27mm_Vertical; MFR PN 20021111-00010T4LF; JLCPCB PN C239059
J3: USB_B_Micro; USB_Micro-B_Amphenol_10103594-0001LF_Horizontal; MFR PN 10103594-0001LF; JLCPCB PN C428495
J4: Conn_01x03_Pin; PinHeader_1x03_P2.54mm_Vertical; MFR PN 2.54-1*3PPin; JLCPCB PN C49257
U1: STM32F407VGTx; LQFP-100_14x14mm_P0.5mm; MFR PN STM32F407VGT6; JLCPCB PN C919362
U2: SN74LV1T34DBV; SOT-23-5; MFR PN SN74LV1T34DBV; JLCPCB PN C100024
Y1: 8MHz Crystal; Crystal_SMD_3225-4Pin_3.2x2.5mm; MFR PN 1C208000BC0R; JLCPCB PN C57131

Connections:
+3.3V: C8.2, C10.1, C12.1, C13.2, C14.2, C15.2, C19.2, C20.2, C21.1, U1.6 (VBAT), U1.11 (VDD), U1.19 (VDD), U1.21 (VREF+), U1.22 (VDDA), U1.28 (VDD), U1.50 (VDD), U1.75 (VDD), U1.100 (VDD); also elsewhere on the board
+5V: C7.1, U2.5 (VCC); also elsewhere on the board
+24V: J4.3; also elsewhere on the board
GND: C7.2, C8.1, C9.2, C10.2, C11.2, C12.2, C13.1, C14.1, C15.1, C16.2, C17.1, C18.2, C19.1, C20.1, C21.2, C22.2, J2.8 (GND), J2.10 (GND), J3.4 (ID), J3.5 (GND), J3.6 (Shield), J4.1, U1.10 (VSS), U1.20 (VSSA), U1.27 (VSS), U1.74 (VSS), U1.94 (BOOT0), U1.99 (VSS), U2.3 (GND), Y1.2 (G), Y1.4 (G); also elsewhere on the board
NRST: C18.1, J2.9 (RESET), U1.14 (NRST)
unnamed: C16.1, U1.12 (PH0), Y1.1
unnamed: C17.2, U1.13 (PH1), Y1.3
unnamed: C9.1, U1.49 (VCAP_1)
unnamed: C11.1, U1.73 (VCAP_2)
PWM_3V3: U1.32 (PA7), U2.2 (A)
PWM_5V5: J4.2, U2.4 (Y)
SWDCLK: J2.5 (SWDCLK), U1.76 (PA14)
SWDIO: J2.3 (SWDIO), U1.72 (PA13)
SWO: J2.7 (SWO), U1.89 (PB3)
UART_RX: J2.1 (UART_RX), U1.79 (PC11)
UART_TX: J2.2 (UART_TX), U1.78 (PC10)
USB_DM: J3.2 (D-), U1.70 (PA11)
USB_DP: J3.3 (D+), U1.71 (PA12)
VBUS: C22.1, J3.1 (VBUS), U1.68 (PA9)

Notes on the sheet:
Micro-B USB Audio
Level Shifter to 3-Pin Header
SWD and UART CLI
Every VDD pin, VBAT, and VDDA require 100nF bypass as close as phyiscally possible VBAT and VDDA also recommend 1uF

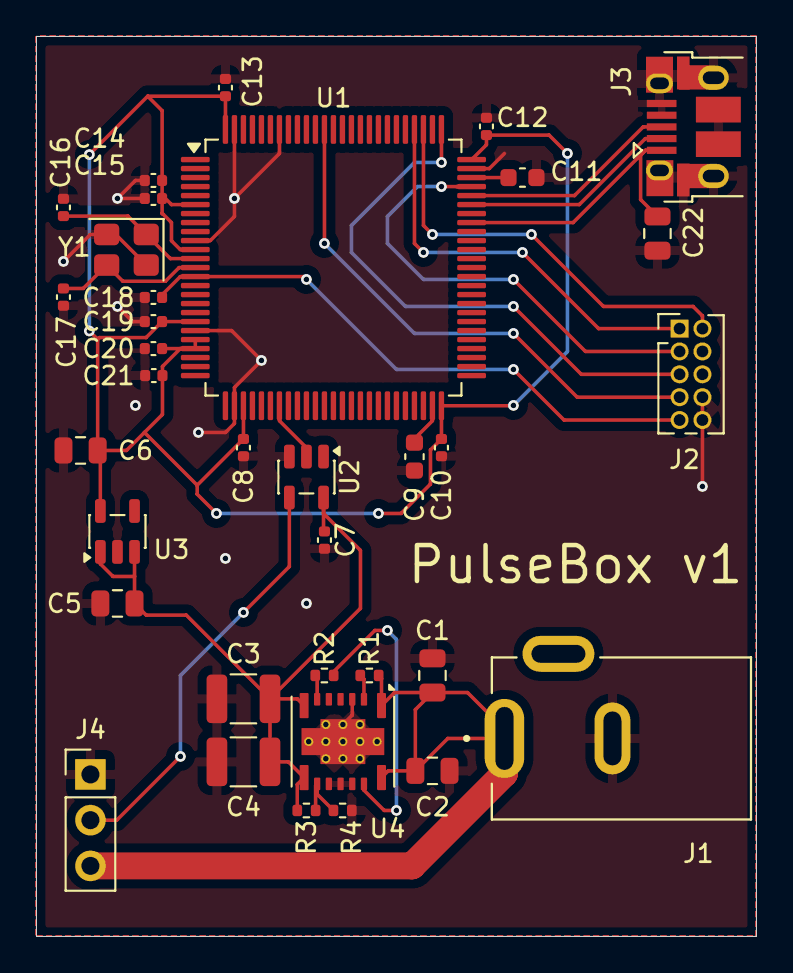
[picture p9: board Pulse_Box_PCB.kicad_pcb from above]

Board: 2 copper layers, 40.0 x 50.0 mm, 35 parts (0 on the bottom side), 23 nets.

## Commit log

2026-02-16 initial commit with all kicad files for v1 pcb
    [BOM_Pulse_Box_PCB_v1.csv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]
2026-02-16 organize schematic into power and signal pages, fixed wire nests
    [Power.kicad_sch, Pulse_Box_PCB.kicad_pcb, Pulse_Box_PCB.kicad_sch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]
2026-02-28 add v2 board design with esp32-s3 wroom module, moved versions into dedicated directories
    [BOM_Pulse_Box_PCB_v1.csv, Power.kicad_sch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]
2026-03-10 add design for pulsebox panel, update v2 PCB to remove 485 trans
    [Pulse_Box_PCB_v2-B_Cu.gbr, Pulse_Box_PCB_v2-B_Mask.gbr, Pulse_Box_PCB_v2-B_Silkscreen.gbr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]
2026-03-14 complete v2 and v1 panel design, this is the final design sent to jlcpcb for v2
    [BOM_Pulse_Box_PCB_v2.csv, BOM_Pulse_Box_Panel_v1.csv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]
2026-04-23 basic readme with board summaries
    [Pulse_Box_Panel_v1.kicad_pcb, signals.kicad_sch]
2026-04-23 upload board images to github, update readme
